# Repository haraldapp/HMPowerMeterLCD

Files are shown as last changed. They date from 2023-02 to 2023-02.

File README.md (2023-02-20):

# HMPowerMeterLCD
Smarthome Energie Zähler mit Impulseingängen  
Status: Prototyp im Dauertest

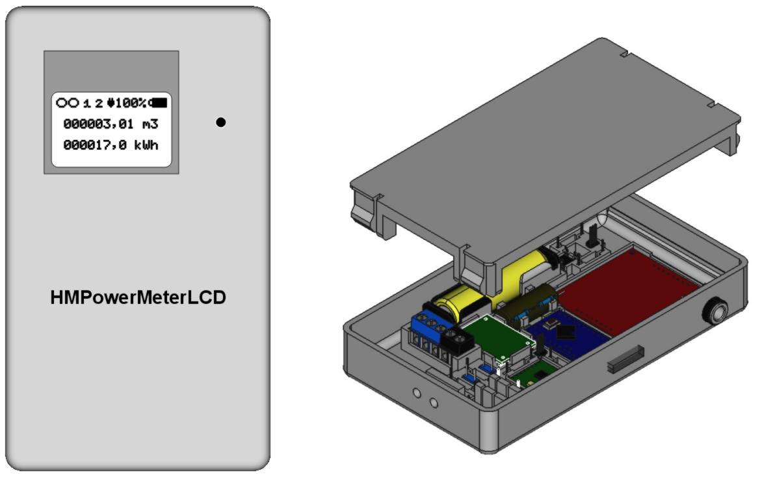
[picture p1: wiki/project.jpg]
 
 

##  Features
- LCD Display mit Menüsteuerung
- 2 getrennte Impluseingänge für 2 Zähler
- LiFePo4 Akku zum Betrieb oder zur Überbrückung von Spannungsausfällen
- Eingabemöglichkeit des aktuellen Zählerstands, um den Wert vom Zähler am Display und an der Zentrale anzuzeigen

## Hardware
- Arduino Pro Mini 3,3V
- LCD Display 84x48 (z.B. Nokia 5110)
- CC1101 Modul
- LiFePo4 AA Akku mit Batteriehalter
- TP5000 Lademodul
- 3DPrint Gehäuse zum Prototypenaufbau mit Verdrahtung direkt im Gehäuse

## Software
- [ASKSINPP](https://github.com/pa-pa/AskSinPP) basierender ARDUINO Sketch auf Basis [HM-ES-TX-WM]( https://github.com/jp112sdl/Beispiel_AskSinPP/tree/master/examples/HM-ES-TX-WM_CCU)
- Umfangreiche Displayanzeige von LED Status, Eingang Status, Batterie und Zählerständen
- Menüsteuerung zur Eingabe des aktuellen Zählerstand
- Permanente Speicherung des Zählerstand mit Backup im EEPROM

## Getting Started
- Schaltplan [```PDF```](/schematic/HMPowerMeterSchematic.pdf) [```JPG```](/schematic/HMPowerMeterSchematic.jpg)
- Verdrahtung (Beispiel) [```JPG```](/schematic/HMPowerMeterWire.jpg)
- Gehäuse: [```JPG1```](/wiki/case-1.jpg) [```JPG2```](/wiki/case-2.jpg) 3D-Druck Dateien im Verzeichnis *case* [```STL1```](/case/HMPowerMeterCase1.stl) [```STL2```](/case/HMPowerMeterCase2.stl)
- Sketch [```ino```](/HMPowerMeterLCD.ino)
- Details ..folgen noch..

## Lizenz
- [Creative Commons 3.0](http://creativecommons.org/licenses/by-nc-sa/3.0/de/)

## 
**Thanks to**
+ [pa-pa](https://github.com/pa-pa) für seine umfangreiche Arbeit
+ [Jérôme](https://github.com/jp112sdl) für seine umfangreiche Arbeit
+ [JurgenO](https://github.com/JurgenO) for seine Ideen und Arbeit -> [GasMetering](https://github.com/JurgenO/GasMetering)

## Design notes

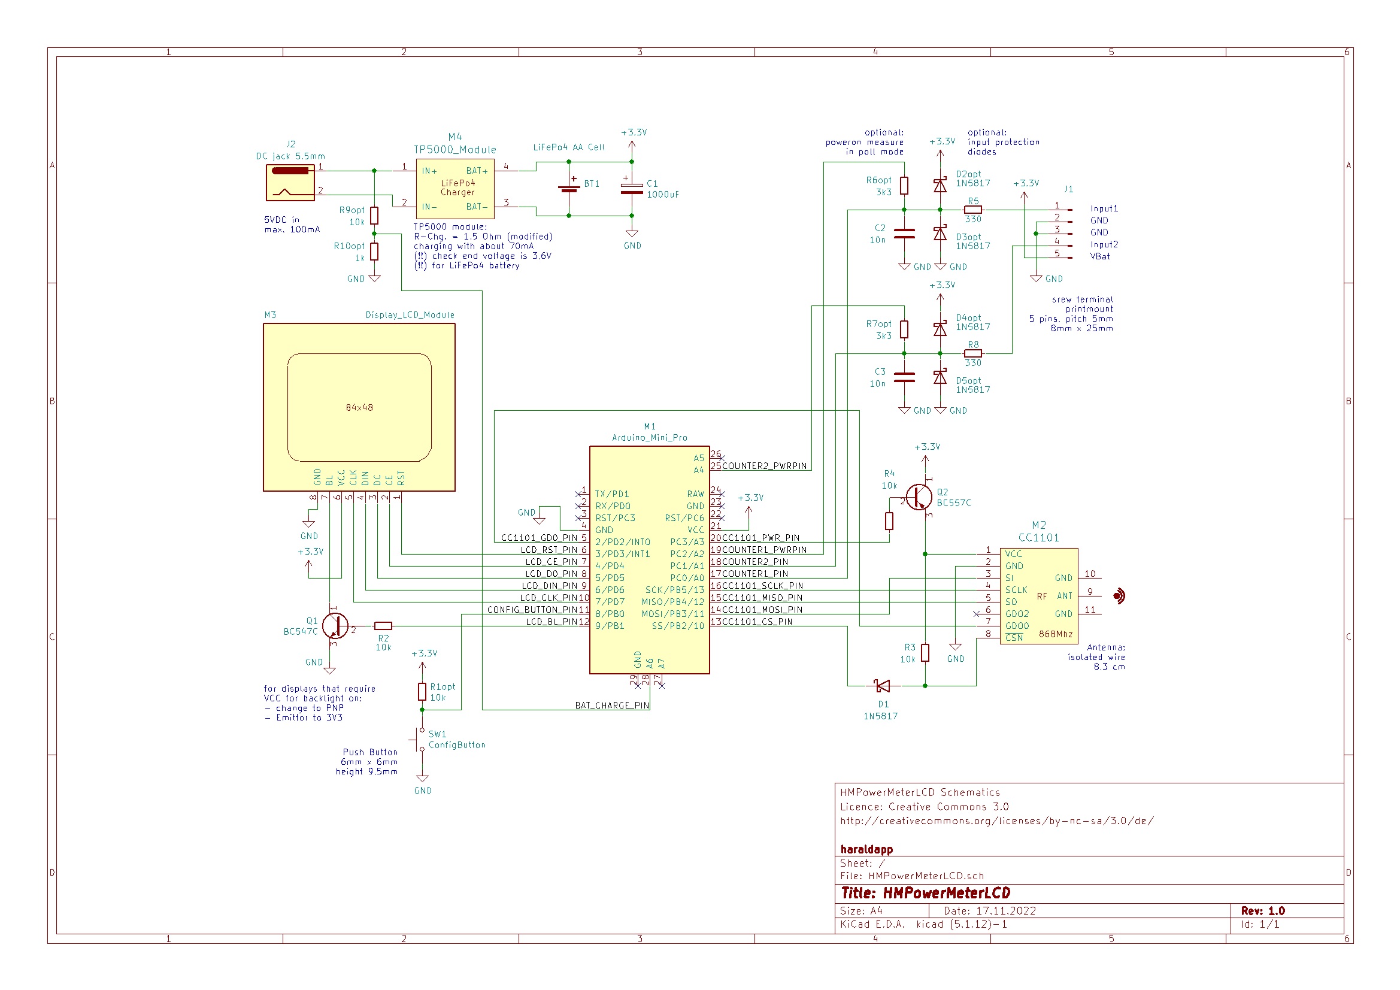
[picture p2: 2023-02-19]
schematic/HMPowerMeterSchematic.jpg

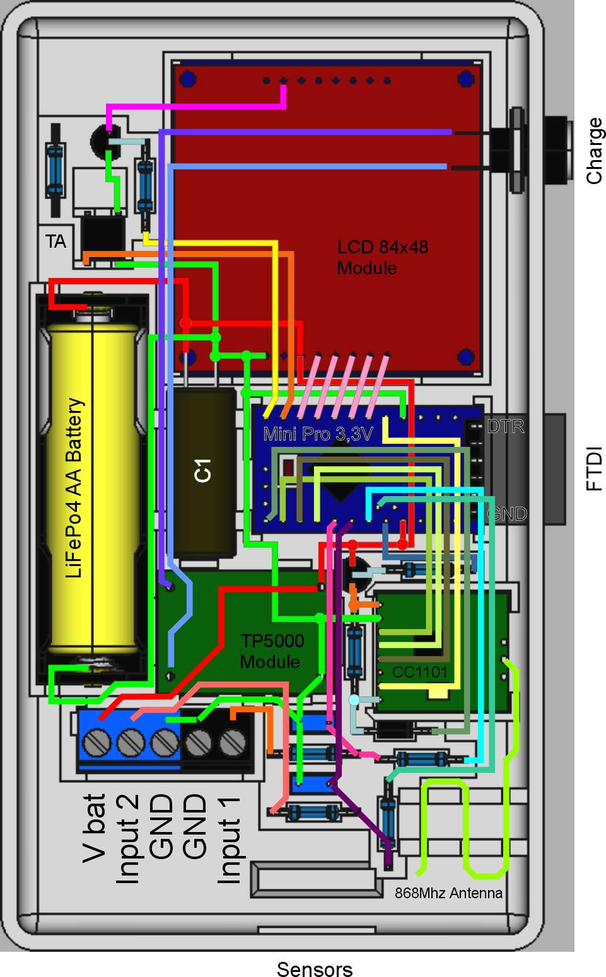
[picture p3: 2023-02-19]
schematic/HMPowerMeterWire.jpg

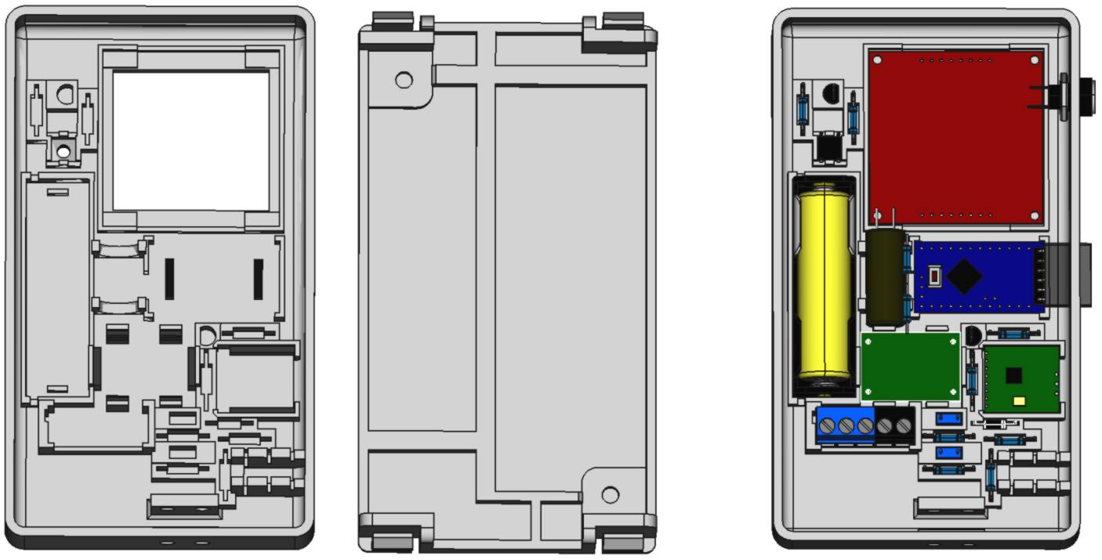
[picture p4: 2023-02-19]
wiki/case-2.jpg

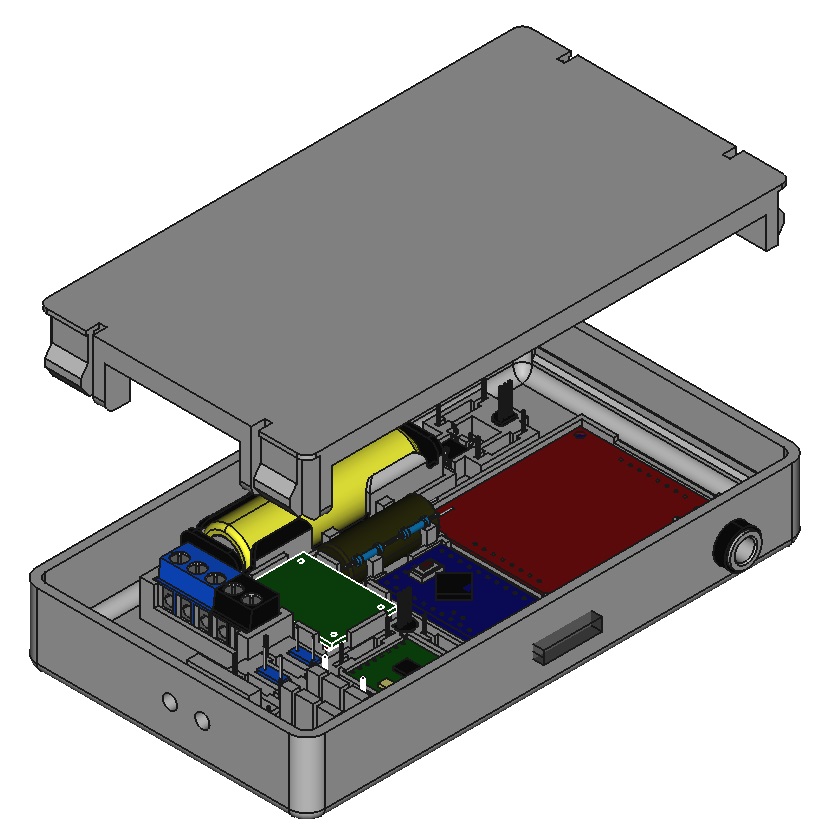
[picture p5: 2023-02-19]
wiki/case-1.jpg

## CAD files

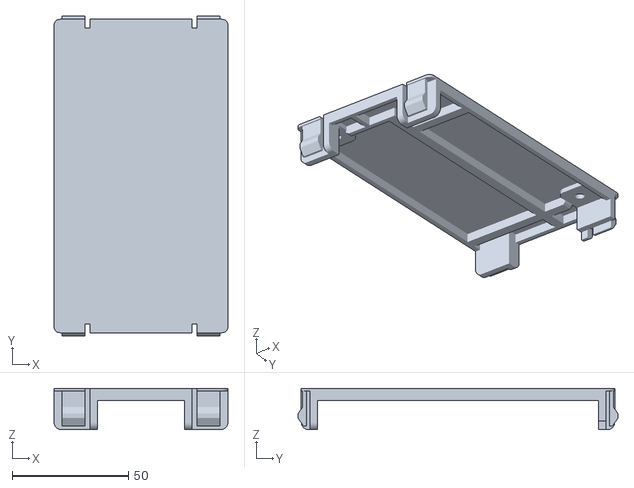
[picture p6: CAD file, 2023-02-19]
case/HMPowerMeterCase2.stl
74.8 x 137.5 x 17.8

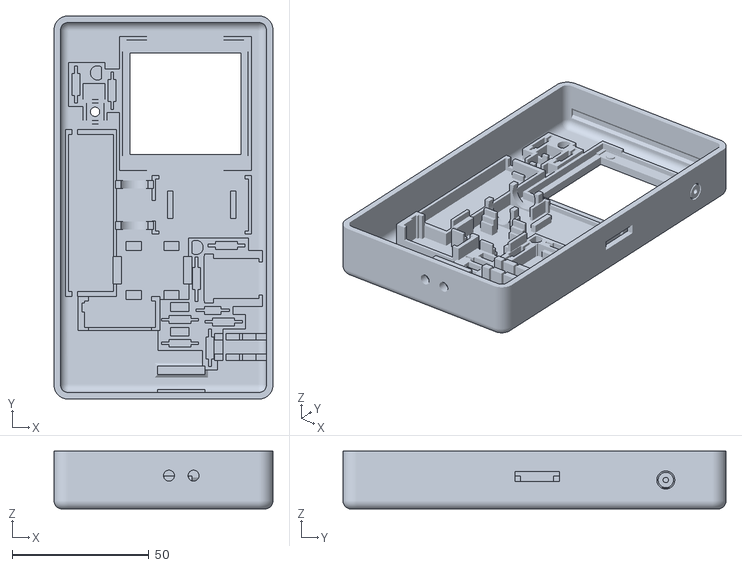
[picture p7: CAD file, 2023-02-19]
case/HMPowerMeterCase1.stl
80.0 x 140.0 x 21.2

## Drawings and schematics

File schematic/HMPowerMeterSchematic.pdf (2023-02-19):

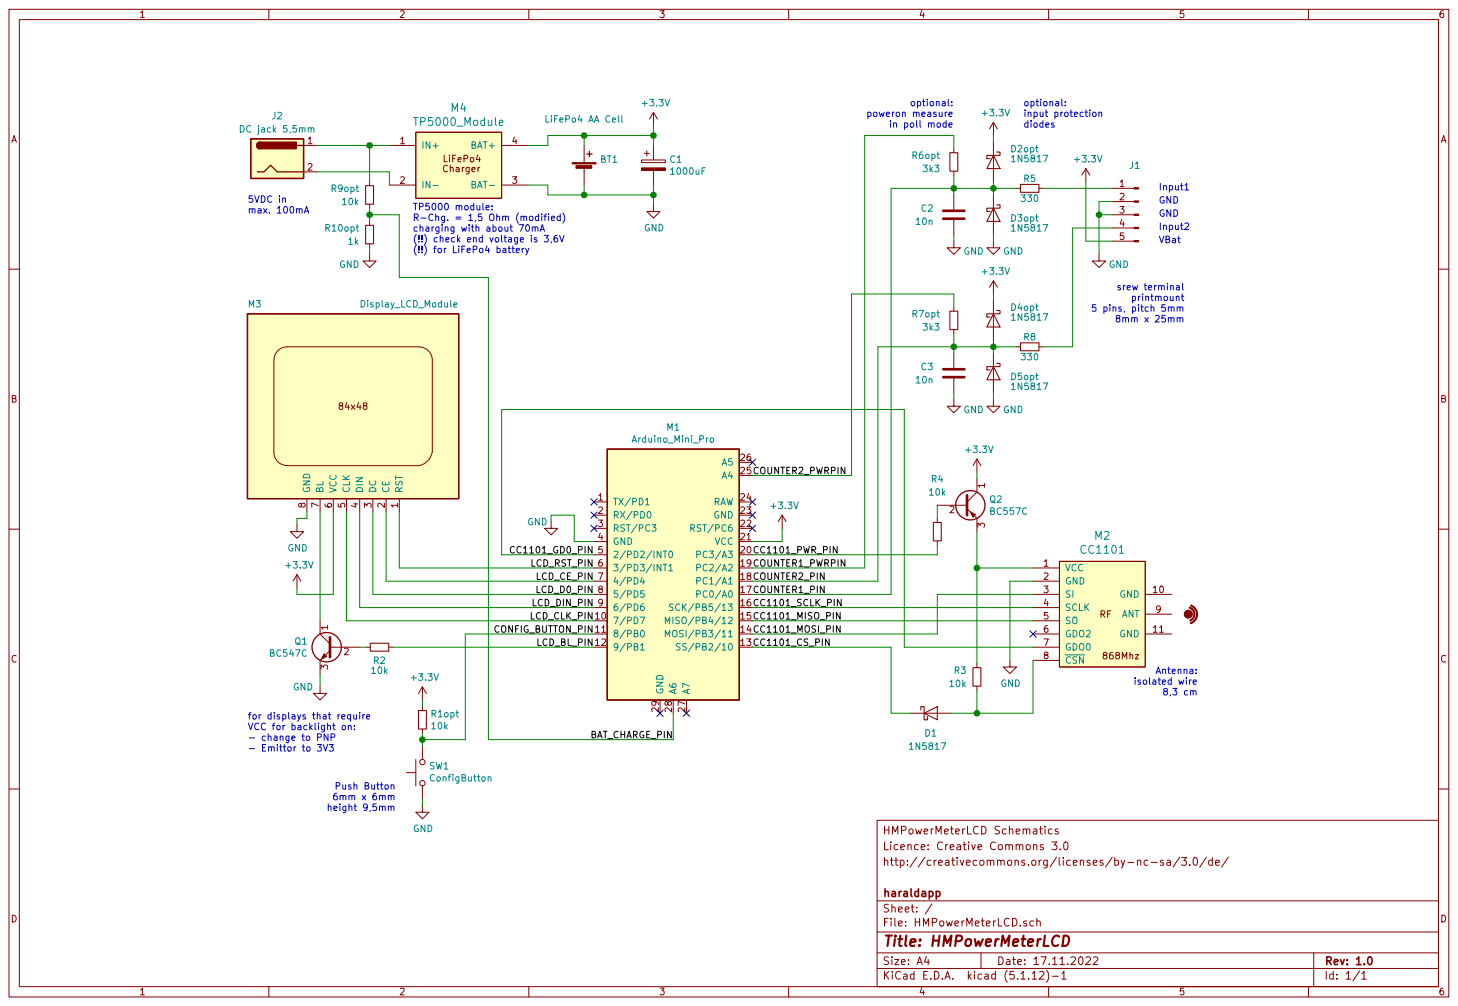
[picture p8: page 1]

TP5000 module: R-Chg. = 1,5 Ohm (modified)

charging with about 70mA
(!!) check end voltage is 3,6V
(!!) for LiFePo4 battery

LCD_CE_PIN | 4/PD4 7 | COUNTER2_PIN
LCD_D0_PIN | 5/PD5 8 | COUNTER1_PIN
LCD_DIN_PIN | | CC1101_SCLK_PIN
LCD_CLK_PIN | | CC1101_MISO_PIN

CONFIG_BUTTON_PIN | | CC1101_MOSI_PIN

LCD_BL_PIN | | CC1101_CS_PIN

for displays that require
VCC for backlight on:
- change to PNP
- Emittor to 3V3

File: HMPowerMeterLCD.sch Sheet: / haraldapp

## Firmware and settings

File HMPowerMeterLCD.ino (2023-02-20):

//- -----------------------------------------------------------------------------------------------------------------------
// HMPowerMeterLCD
//
// The following code is derived from the AskSinPP [1] sample HM-ES-TX-WM [2].
// 
// Author: H. Appelt, December 2022
// License: Creative Commons - http://creativecommons.org/licenses/by-nc-sa/3.0/de/
// 
// REFERENCES
// [1] AskSinPP https://github.com/pa-pa/AskSinPP and https://asksinpp.de/
// [2] HM-ES-TX-WM_CCU  https://github.com/jp112sdl/Beispiel_AskSinPP/tree/master/examples/HM-ES-TX-WM_CCU
// [3] EnableInterrupt https://github.com/GreyGnome/EnableInterrupt
// [4] Nokia 5110 LCD Library  https://github.com/platisd/nokia-5110-lcd-library/

#define PM_VERSION_MAJOR 1
#define PM_VERSION_MINOR 0
#define PM_VERSION_STR STRINGIZE(PM_VERSION_MAJOR) "." STRINGIZE(ASKSIN_PLUS_PLUS_MINOR)

// development
#define NDEBUG     // change to get debug output
#define SAVEPOWER  // change to use Idle instead Sleep to save power (for debug)
#define NDEBUGBAT  // change to transmit battery voltage as actualConsumption to the CCU (and may get a discharge diagram)

// #define USE_OTA_BOOTLOADER // define this to read the device id, serial and device type from bootloader section
#define EI_NOTEXTERNAL
#include <EnableInterrupt.h>
#include <AskSinPP.h>
#include <LowPower.h>
#include <Nokia_LCD.h>
#include <MultiChannelDevice.h>
using namespace as; // all library classes are placed in the namespace 'as'

// define device properties
const struct DeviceInfo PROGMEM devinfo = {
    {0x90,0x12,0x14},       // Device ID
    "HGAS901214",           // Device Serial
    {0x00,0xde},            // Device Model
    0x12,                   // Firmware Version
    as::DeviceType::PowerMeter, // Device Type
    {0x01,0x00}             // Info Bytes
};

// we use a Pro Mini and..
//  a single config button
#define CONFIG_BUTTON_PIN 8 // PB0
//  no LEDs (LED states are shown on the LCD display, for debug buildin LED is used)
//    #define LED_PIN A5
//  a CC1101 module with poweron switch
#define CC1101_CS_PIN   10
#define CC1101_MOSI_PIN 11
#define CC1101_MISO_PIN 12
#define CC1101_SCLK_PIN 13
#define CC1101_GD0_PIN   2
#define CC1101_PWR_PIN  17
//  a LCD display 84x48 pixel (eg. NOKIA 5110 or clones)
#define LCD_RST_PIN       3
#define LCD_CE_PIN        4
#define LCD_D0_PIN        5
#define LCD_DIN_PIN       6
#define LCD_CLK_PIN       7
#define LCD_BL_PIN        9     // backlight pin
#define LCD_BL_ONSTATE    HIGH  // backlight "on" pin state
#define LCD_CONTRAST      55    // typcal values are 40-60
#define BACKLIGHT_TIMEOUT 30    // sec
#define MENU_TIMEOUT      30    // sec
//  a LiFePo4 AA battery (w/o voltage regulator) and a TP5000 charging module (values in mV)
//    (!)check(!) that yout charger ends charge at 3,6V or you may destoy the CC1101 module and the battery
//    .. some TODO's (eg. check and implement temperature dependency for battery discharge curve)
//    .. test battery time - at the moment the battery is used for backup during power fail
#define BAT_CHARGE_PIN       A6   // Pin used to measure VDCin voltage to see if we are charging
#define BAT_ADC_INTERNAL_REF 1061 // measured ADC internal ref to calibrate ADC result (should be around 1100mV)
#define BAT_LOW              3130 // for CCU message
#define BAT_CRITICAL         3060 // critical level, go to sleep forever
#define BAT_CALC_FULL        3235 // values recorded at 18°C and CC1101 in on state
#define BAT_CALC_EMPTY       3100 
#define BAT_CALC_CURVE_D     {3235,3230,3225,3210,3200,3195,3185,3170,3150,3110,3090} // discharge 100% -> 0% (comment out to use linear calculation)
#define BAT_CALC_CURVE_C     {3410,3355,3345,3337,3300,3320,3310,3305,3290,3250,3210} // charge 100% -> 0% 
//  two counter inputs (reed or other contact to GND)
//  - two modes to detect a counter impuse
//    1: ISR trigger with sleep wakeup (original code)
//       requires a internal or external pullup resistor
//       disadvantage: some meter types can stay in the contact state "closed" for a long time and consuming power
//    2: Poll the input at a constant rate
//       the pullup resistor can be connected to pwrpin, only activated during a quit short read time
//       disadvantage: only for slow impulse rates, high rate would require a high poll rate consuming power
//  we assume that the generates one implus to increment the lowest digit.. so
//  - no mul/div operations are required to calculate the consumption, just dapat the format string
#define COUNTER1_MODE       2              // 0=none 1=Interrput 2=Poll
#define COUNTER1_PIN        14             // (A0=PIN14 A1=PIN15 A2=PIN16 on Pro Mini)
#define COUNTER1_PINMODE    INPUT          // INPUT_PULLUP or INPUT
#define COUNTER1_PWRPIN     16             // pin to power on measuring, 0xFF=none (poll mode only)
#define COUNTER1_POLL       600            // ms poll interval (poll mode only)
#define COUNTER1_DEBOUNCE   200            // ms
#define COUNTER1_INC        1              // counter increment for one pulse
#define COUNTER1_FORMAT     "######,## m3" // for display: each # is replaced by one digits of the countersum, other chars will be displayed they are
#define COUNTER1_FORMATSIGS 100            // for display: sigs for one pulse *100 (=100 means one pulse increments last digit in display format)
#define COUNTER1_SIGS       10             // for CCU: define to overwrite sigs from CCU config
#define COUNTER1_ICEMUL     1              // for CCU: define extra mutiplicator for counter value (ICE type only)
#define COUNTER2_MODE       1
#define COUNTER2_PIN        15
#define COUNTER2_PINMODE    INPUT_PULLUP
#define COUNTER2_PWRPIN     0xFF  
#define COUNTER2_POLL       600          
#define COUNTER2_DEBOUNCE   200          
#define COUNTER2_INC        1
#define COUNTER2_FORMAT     "######,# kWh"
#define COUNTER2_FORMATSIGS 750            // typical 3-phase meter has 75 rotations for one kWh
#define COUNTER2_SIGS       75
#define COUNTER2_ICEMUL     10000

// send the counter every 2,5 minutes
#define MSG_CYCLE seconds2ticks(2*60+30)
// after boot send counters imediate (so when testing we do not have to wait)
#define FIRST_MSG_CYCLE seconds2ticks(4)
// number of available peers per channel
#define PEERS_PER_CHANNEL 2

// NOKIA LCD display
//  bitmaps: each byte is a vertical line of 8 pixels (first byte is left, bit0 is top)
const uint8_t PMDisplaySymLedOff[9] PROGMEM= {
  B00011100, B00100010, B01000001, B01000001, B01000001, B01000001, B00100010, B00011100, B00000000, };
const uint8_t PMDisplaySymLed1On[9] PROGMEM= {
  B00011100, B00111110, B01111111, B01111111, B01111111, B01111111, B00111110, B00011100, B00000000, };
const uint8_t PMDisplaySymLed2On[9] PROGMEM= {
  B00011100, B00101010, B01010101, B01101011, B01010101, B01101011, B00101010, B00011100, B00000000, };
const uint8_t PMDisplaySymInput1Off[9] PROGMEM= {
  B00000000, B00000000, B01001000, B01000100, B00111110, B01000000, B01000000, B00000000, B00000000, };
const uint8_t PMDisplaySymInput1On[9] PROGMEM= {
  B01111110, B11111111, B10110111, B10111011, B11000001, B10111111, B10111111, B11111111, B01111110, };
const uint8_t PMDisplaySymInput2Off[9] PROGMEM= {
  B00000000, B00000000, B01000100, B01100010, B01010010, B01001010, B01000100, B00000000, B00000000, };
const uint8_t PMDisplaySymInput2On[9] PROGMEM= {
  B01111110, B11111111, B10111011, B10011101, B10101101, B10110101, B10111011, B11111111, B01111110, };
const uint8_t PMDisplaySymBat[15] PROGMEM= {
  B00000000, B00011100, B00100010, B00100010, B01111111, B01000001, B01000001, B01000001, 
  B01000001, B01000001, B01000001, B01000001, B01000001, B01000001, B01111111, };
const uint8_t PMDisplaySymBatH[8] PROGMEM= {
  B01001001, };
const uint8_t PMDisplaySymBatV[8] PROGMEM= {
  B01111111, };
const uint8_t PMDisplaySymBatCharge[6] PROGMEM= {
  B00011100, B00111111, B01111100, B00111111, B00011100, B00000000 };
const uint8_t PMDisplaySymBatNoCharge[6] PROGMEM= {
  B00000000, B00000000, B00000000, B00000000, B00000000, B00000000, };
const uint8_t PMDisplaySymMenuPosNone[6] PROGMEM= {
  B00000000, B00000000, B00000000, B00000000, B00000000, B00000000, };
const uint8_t PMDisplaySymMenuPosLeft[6] PROGMEM= {
  B01111111, B00111110, B00011100, B00011100, B00001000, B00000000, };
const uint8_t PMDisplaySymMenuPosTop[6] PROGMEM= {
  B00110000, B00111100, B00111110, B00111100, B00110000, B00000000, };
const uint8_t PMDisplaySymMenuPosEdit[6] PROGMEM= {
  B00110000, B00111000, B00011100, B01001110, B00000101, B01000010, };

//  display pages: 
//    the default (amin) page is drawn by code
//    other pages have a DISPLAY_MENU_DEF with text and menu marker definitions
enum { DISPLAY_PAGE_DEFAULT=0, DISPLAY_PAGE_WELCOME, DISPLAY_PAGE_CC1101ERROR, DISPLAY_PAGE_MENU1, DISPLAY_PAGE_RESETDEVICE,
       DISPLAY_PAGE_SETCOUNTER1, DISPLAY_PAGE_SETCOUNTER2 };
enum { DISPLAY_MENUDIR_NONE=0, DISPLAY_MENUDIR_LEFT, DISPLAY_MENUDIR_TOP };
enum { DISPLAY_MENU_END=0xFF, DISPLAY_MENU_NONE=0xFE, DISPLAY_MENU_WRAP=0xFD };
enum { DISPLAY_MENU_CANCEL,
       DISPLAY_MENU_SETCOUNTER1=10, DISPLAY_MENU_SETCOUNTER2, DISPLAY_MENU_SAVECOUNTERS, DISPLAY_MENU_STARTPAIRING, DISPLAY_MENU_RESETDEVICE,
       DISPLAY_MENU_SAVECOUNTER1=20, DISPLAY_MENU_SAVECOUNTER2,
       DISPLAY_MENU_RESETCONFIRM=30, 
       DISPLAY_MENU_COUNTERPOS_FIRST=100, DISPLAY_MENU_COUNTERPOS_LAST=120,
};
typedef struct { uint8_t menu; uint8_t textx; uint8_t texty; const char *text; uint8_t menux; uint8_t menuy; uint8_t menudir;  } DISPLAY_MENU_DEF;
static const DISPLAY_MENU_DEF _display_welcome_def[]={
  // menuitemid                textpos    text        markerpos    markertype
  { DISPLAY_MENU_NONE,          1, 2, "HMPowerMeter" },
  { DISPLAY_MENU_NONE,          5, 3, PM_VERSION_STR },
  { DISPLAY_MENU_END },
};
static const DISPLAY_MENU_DEF _display_cc1101error_def[]={
  // menuitemid                textpos    text        markerpos    markertype
  { DISPLAY_MENU_NONE,          4, 2, "CC1101" },
  { DISPLAY_MENU_NONE,          4, 3, "error" },
  { DISPLAY_MENU_END },
};
static const DISPLAY_MENU_DEF _display_menu1_def[]={
  // menuid/action             textpos    text        markerpos    markertype
  { DISPLAY_MENU_SETCOUNTER1,   1, 1, "set counter1", 0, 1, DISPLAY_MENUDIR_LEFT },
  { DISPLAY_MENU_SETCOUNTER2,   1, 2, "set counter2", 0, 2, DISPLAY_MENUDIR_LEFT },
  { DISPLAY_MENU_SAVECOUNTERS,  1, 3, "save counters", 0, 3, DISPLAY_MENUDIR_LEFT },
  { DISPLAY_MENU_STARTPAIRING,  1, 4, "start pairing", 0, 4, DISPLAY_MENUDIR_LEFT },
  { DISPLAY_MENU_RESETCONFIRM,  1, 5, "reset device" , 0, 5, DISPLAY_MENUDIR_LEFT },
  { DISPLAY_MENU_END },
};
static const DISPLAY_MENU_DEF _display_resetconfirm_def[]={
  { DISPLAY_MENU_NONE,          0, 2, "reset device?" },
  { DISPLAY_MENU_CANCEL,        1, 4, "cancel",        0, 4, DISPLAY_MENUDIR_LEFT },
  { DISPLAY_MENU_RESETDEVICE,   1, 5, "ok",            0, 5, DISPLAY_MENUDIR_LEFT },
  { DISPLAY_MENU_WRAP },
};
static const struct { uint8_t page; const DISPLAY_MENU_DEF *pagemenu; } _display_page2menu[]={
  { DISPLAY_PAGE_WELCOME, _display_welcome_def },
  { DISPLAY_PAGE_CC1101ERROR, _display_cc1101error_def },
  { DISPLAY_PAGE_MENU1, _display_menu1_def },
  { DISPLAY_PAGE_RESETDEVICE, _display_resetconfirm_def },
};

#define DISPLAY_WIDTH  84
#define DISPLAY_HEIGHT 48
#define CHAR_WIDTH      6 // including one right empty column as sep
#define CHAR_HEIGHT     8
#define DISPLAY_ROWS    (DISPLAY_HEIGHT/CHAR_HEIGHT) // 6
#define DISPLAY_COLS    (DISPLAY_WIDTH/CHAR_WIDTH) // 14
class PMDisplay : public Alarm,  protected Nokia_LCD {
protected:
  uint8_t backlightstate;
  uint8_t led1state, led2state;
  uint8_t input1state, input2state;
  uint8_t batterystate, batterycharge;
  uint64_t sum1, sum2;
  enum { FLAG_LED1=1, FLAG_LED2=2, FLAG_INPUT1=4, FLAG_INPUT2=8, FLAG_BAT=16, FLAG_SUM1=32, FLAG_SUM2=64, FLAG_BKGND=128, FLAG_MENUPOS=256, FLAG_EDITLINE=512 };
  uint16_t dirty;
  int8_t currentpage, currentmenupos;
  const DISPLAY_MENU_DEF *currentmenudef; uint8_t currentmenudefnonestatic;
  uint8_t menuedit;
  char countereditline[DISPLAY_COLS+1];
public:
  PMDisplay() : Alarm(0), Nokia_LCD(LCD_CLK_PIN,LCD_DIN_PIN,LCD_D0_PIN,LCD_CE_PIN,LCD_RST_PIN,LCD_BL_PIN) {
    backlightstate=0;
    led1state=0; led1state=0; 
    input1state=0; input2state=0;
    batterystate=0xFF;
    batterycharge=0;
    sum1=0; sum2=0;
    dirty=0xFF;
    currentpage=DISPLAY_PAGE_DEFAULT; currentmenupos=0;
    currentmenudef=0; currentmenudefnonestatic=0;
    menuedit=0;
  }
  void init( uint8_t input1init=0, uint8_t input2init=0 ) {
    input1state=input1init; input2state=input2init;
    begin(); // initialize the screen
    setContrast( LCD_CONTRAST );  // initialize contrast
    clear( false ); // clear the screen
    setpage( DISPLAY_PAGE_WELCOME, 3 ); update();
  }
  void initdone() {
    setpage( DISPLAY_PAGE_DEFAULT ); 
  }
  void setbacklight( uint8_t newstate ) {
    backlightstate=newstate; setBacklight(newstate);
  }
  void tooglebacklight() {
    backlightstate=(backlightstate?0:1); setBacklight(backlightstate);
  }
  uint8_t getbacklight() const {
    return backlightstate;
  }
  void setled( uint8_t lednr, uint8_t newstate ) {
    ATOMIC_BLOCK( ATOMIC_RESTORESTATE ) {
      uint8_t& state=(lednr==1?led1state:led2state);
      if ( state!=newstate ) { state=newstate; dirty|=(lednr==1?FLAG_LED1:FLAG_LED2); }
    }
  }
  uint8_t getled( uint8_t lednr, uint8_t removedirty=0 ) {
    volatile uint8_t ret;
    ATOMIC_BLOCK( ATOMIC_RESTORESTATE ) {
      ret=(lednr==1?led1state:led2state);
      if ( removedirty )  dirty&=(lednr==1?(~FLAG_LED1):(~FLAG_LED2));
    }
    return ret;
  }
  void setinput( uint8_t inputnr, uint8_t newstate ) {
    ATOMIC_BLOCK( ATOMIC_RESTORESTATE ) {
      uint8_t& state=(inputnr==1?input1state:input2state);
      if ( state!=newstate ) { state=newstate; dirty|=(inputnr==1?FLAG_INPUT1:FLAG_INPUT2); }
    }
  }
  void setbatterystate( uint8_t newstate ) {
    if ( batterystate!=newstate ) { batterystate=newstate; setdirty(FLAG_BAT); }
  }
  void setbatterycharge( uint8_t newstate ) {
    if ( batterycharge!=newstate ) { batterycharge=newstate; setdirty(FLAG_BAT); }
  }
  void setcounter( uint8_t channelnr, uint64_t newsum ) {
    uint64_t& sum=(channelnr==1?sum1:sum2);
    uint32_t sigs=(channelnr==1?COUNTER1_FORMATSIGS:COUNTER2_FORMATSIGS);
    sum=(newsum*100)/sigs;
    setdirty(channelnr==1?FLAG_SUM1:FLAG_SUM2);
  }
  void setpage( uint8_t newpage, uint8_t page_timeout_sec=0 ) {
    // DPRINT(F("setpage ")); DDECLN(newpage);
    uint16_t flags=0;
    if ( currentpage!=newpage )  { 
      currentpage=newpage; currentmenupos=-1; flags|=FLAG_BKGND; menuedit=0;
      setmenudef(0);
      // static page definitions
      for ( uint8_t i=0; i<sizeof(_display_page2menu)/sizeof(_display_page2menu[0]); i++ )
        if ( _display_page2menu[i].page==newpage )
          setmenudef( _display_page2menu[i].pagemenu );
      // dynamic page definitions
      if ( !currentmenudef && newpage==DISPLAY_PAGE_SETCOUNTER1 )
         createsetcountermenu( DISPLAY_MENU_SAVECOUNTER1, sum1, COUNTER1_FORMAT );
      if ( !currentmenudef && newpage==DISPLAY_PAGE_SETCOUNTER2 )
         createsetcountermenu( DISPLAY_MENU_SAVECOUNTER2, sum2, COUNTER2_FORMAT );
      nextmenupos(); // init first position
      if ( page_timeout_sec>0 ) {
        sysclock.cancel(*this); // set page timeout 
        tick=seconds2ticks(page_timeout_sec); sysclock.add(*this);
      }
    }
    setdirty( flags );
  }
  void setmenudef( const DISPLAY_MENU_DEF *pdef, uint8_t nonestatic=0 ) {
    if ( currentmenudef && currentmenudefnonestatic )   free(currentmenudef);
    currentmenudef=pdef; currentmenudefnonestatic=nonestatic;
  }
  uint8_t getpage() const {
    return currentpage;
  }
  uint8_t getmenu() const {
    if ( !currentmenudef )   return DISPLAY_MENU_END;
    if ( currentmenupos>=0 )   return currentmenudef[currentmenupos].menu;
    return DISPLAY_MENU_NONE;
  }
  bool nextmenupos() {
    // DPRINTLN(F("nextmenupos"));
    bool ret=false; uint16_t flags=0;
    while ( currentmenudef && currentmenupos>=-1 )
    {
      if ( currentmenupos>=0 && currentmenudef[currentmenupos].menu==DISPLAY_MENU_END )  return false;
      currentmenupos++; flags|=FLAG_MENUPOS; 
      uint8_t menu=currentmenudef[currentmenupos].menu;
      if ( menu==DISPLAY_MENU_END )  { ret=false; break; }
      else if ( menu==DISPLAY_MENU_WRAP )  currentmenupos=-1;
      else if ( menu!=DISPLAY_MENU_NONE )  { ret=true; break; }
    }
    setdirty( flags );
    return ret;
  }
  bool menuposedit() const { // current menu select is editable
    uint8_t menu=getmenu();
    return (menu>=DISPLAY_MENU_COUNTERPOS_FIRST && menu<=DISPLAY_MENU_COUNTERPOS_LAST);
  }
  uint8_t getmenuedit() const {
    return menuedit;
  }
  void setmenuedit( uint8_t newstate ) {
    if ( newstate!=menuedit )  { menuedit=newstate; setdirty(FLAG_MENUPOS); }
  }
  uint8_t tooglemenuedit() {
    setmenuedit( menuedit?0:1 );
    return menuedit;
  }
  bool nextmenuedit() {
    if ( !menuposedit() )   return false;
    const DISPLAY_MENU_DEF& m=currentmenudef[currentmenupos];    
    if ( m.menu>=DISPLAY_MENU_COUNTERPOS_FIRST && m.menu<=DISPLAY_MENU_COUNTERPOS_LAST ) {
      return incrementcounterdigit( m.menux );
    }
    return false;
  }
  bool getmenueditvalue( uint64_t& val, uint8_t updateval=1 ) {
    bool ret=false; uint8_t channelnr=0;
    if ( currentpage==DISPLAY_PAGE_SETCOUNTER1 ) {
      ret=true; channelnr=1; val=getcounterline( countereditline, COUNTER1_FORMAT );
      val=(val*COUNTER1_FORMATSIGS)/100;
    }
    else if ( currentpage==DISPLAY_PAGE_SETCOUNTER2 ) {
      ret=true; channelnr=2; val=getcounterline( countereditline, COUNTER2_FORMAT );
      val=(val*COUNTER2_FORMATSIGS)/100;
    } 
    if ( ret && updateval )
      setcounter( channelnr, val );
    return ret;
  }
  void setdirty( uint16_t flags ) {
    ATOMIC_BLOCK( ATOMIC_RESTORESTATE ) { 
      dirty|=flags;
    }
  }
  bool update() {
    volatile uint16_t flags;  
    ATOMIC_BLOCK( ATOMIC_RESTORESTATE ) { 
      flags=dirty; dirty=0;
    }
    if ( flags&FLAG_LED1 )  drawled(1,getled(1,true));
    if ( flags&FLAG_LED2 )  drawled(2,getled(2,true));
    if ( flags&FLAG_INPUT1 )  drawinput( 1, input1state ); 
    if ( flags&FLAG_INPUT2 )  drawinput( 2, input2state );
    if ( flags&FLAG_BAT )  drawbattery( batterystate, batterycharge );
    if ( currentpage==DISPLAY_PAGE_DEFAULT ) {
        if ( flags&FLAG_BKGND )              clearrows();
        if ( flags&(FLAG_SUM1|FLAG_BKGND) )  printcounter( 2, sum1, COUNTER1_FORMAT );
        if ( flags&(FLAG_SUM2|FLAG_BKGND) )  printcounter( 4, sum2, COUNTER2_FORMAT );
    } else if ( currentmenudef ) {
        if ( flags&FLAG_BKGND ) { clearrows(); flags|=FLAG_MENUPOS|FLAG_EDITLINE|FLAG_SUM1|FLAG_SUM2; }
        const DISPLAY_MENU_DEF *mdef=currentmenudef;
        while ( mdef && mdef->menu!=DISPLAY_MENU_END && mdef->menu!=DISPLAY_MENU_WRAP ) {
          bool editlinedirty=(flags&FLAG_EDITLINE) && (mdef->text==countereditline);
          if ( flags&FLAG_BKGND )    printat( CHAR_WIDTH*mdef->textx, mdef->texty, mdef->text );
          if ( flags&FLAG_MENUPOS )  drawmenupos( CHAR_WIDTH*mdef->menux, mdef->menuy, mdef->menu, mdef->menudir );
          if ( editlinedirty )       printat( CHAR_WIDTH*mdef->textx, mdef->texty, mdef->text );
          mdef++;
        }
    }
    return dirty!=0;
  }
  virtual void trigger( AlarmClock& ) {
    setpage( DISPLAY_PAGE_DEFAULT );
  }
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
void loop() {
  bool worked = hal.runready();
  bool poll = sdev.pollRadio();
  bool displayupdate = display.update();
  if( worked==false && poll==false && displayupdate==false ) {
    if ( hal.battery.critical() ) {
      // if battery is critical: end up all here before getting a bubbling idiot
      PersistMem.save();
      hal.activity.sleepForever(hal);
    }
    #ifdef SAVEPOWER
    hal.activity.savePower< Sleep<> >(hal);
    #else
    hal.activity.savePower< Idle<> >(hal);
    #endif
  }
}
